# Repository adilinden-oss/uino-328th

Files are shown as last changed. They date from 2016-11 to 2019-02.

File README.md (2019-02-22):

## \*uino-328th

The \*uino-328th was designed for my son Mathew. As a mostly though-hole design, it should be easy to assemble even for a beginner.  The only surface mount component is the micro USB connector. Personally I much prefer micro USB over the full sized or mini connector. Unfortunately I was unable to find a through-hole micro USB.  Having the one surface mounted component was a compromise I was willing to take.

The board includes a USB serial bridge based on the PIC16F1454.  Not only is the PIC16F1454 available as a 14 pin though-hole device, it is also considerably less expensive then an ATmega8U2, for example.  

Initially I intend on using the [jgeisler0303/PIC16F1454_USB2Serial](https://github.com/jgeisler0303/PIC16F1454_USB2Serial)  firmware, but ultimately I hope to use the Open Source [signal11/m-stack](https://github.com/signal11/m-stack) as USB serial bridge firmware.

The \*uino-328th is intended to operate at 3.3V.  There are two possible clock sources for the ATmega328P, a dedicated resonator or the clock output of the PIC16F1454.

### Important Note

PCB have been ordered from SeeedStudio FusionPCB service. There is no working sample yet.

### Licensing

This work is licensed under a Creative Commons Attribution-ShareAlike 3.0 Unported License, CC BY-SA.

You are free to copy, distribute and transmit the work. You must attribute the work in the manner specified by the author or licensor (but not in any way that suggests that they endorse you or your use of the work). you alter, transform, or build upon this work, you may distribute the resulting work only under the same or similar license to this one.  

Please refer to [http://creativecommons.org/licenses/by-sa/3.0/] for the license.

### Credit

The \*uino-328th was inspired by:

- The Frienduino [jgeisler0303/Frienduino](https://github.com/jgeisler0303/Frienduino)
- The [Innovation Board](http://make.unl.edu/innovation-board/)

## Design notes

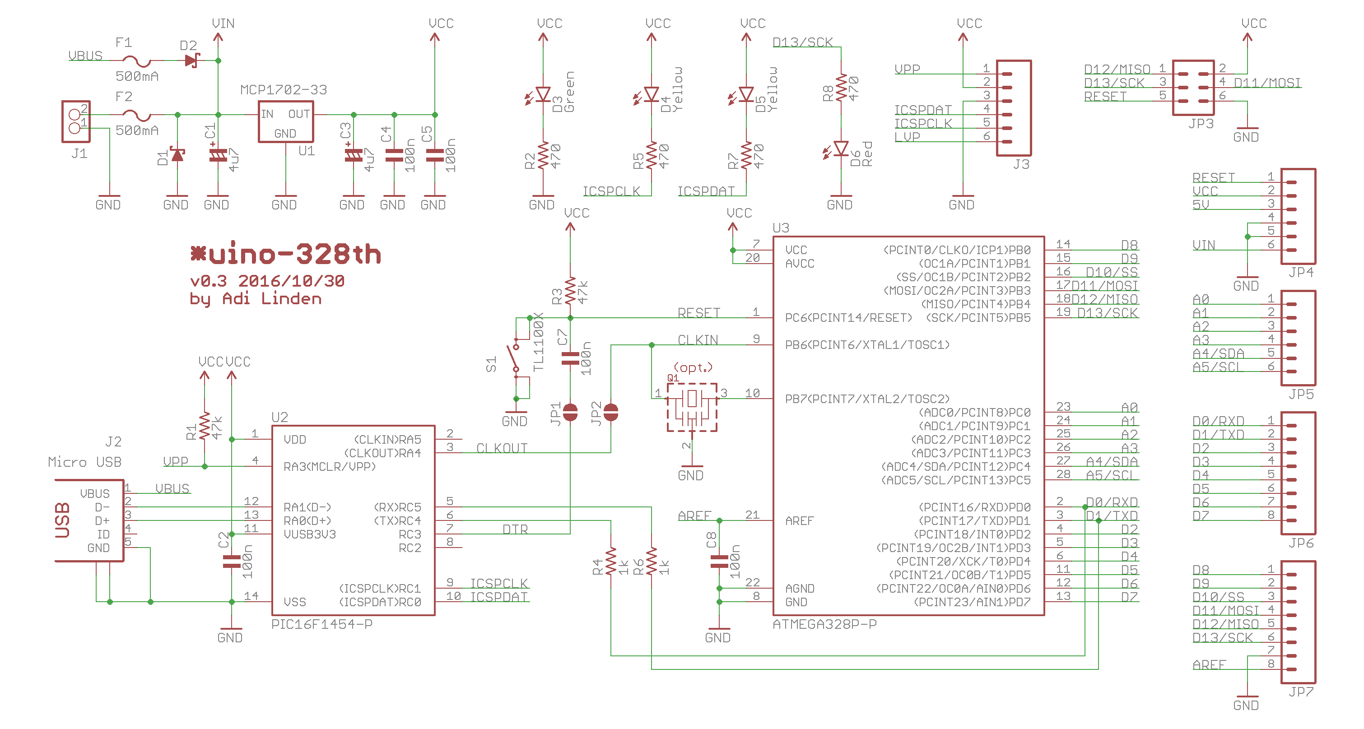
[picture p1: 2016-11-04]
uino-328th-sch.png

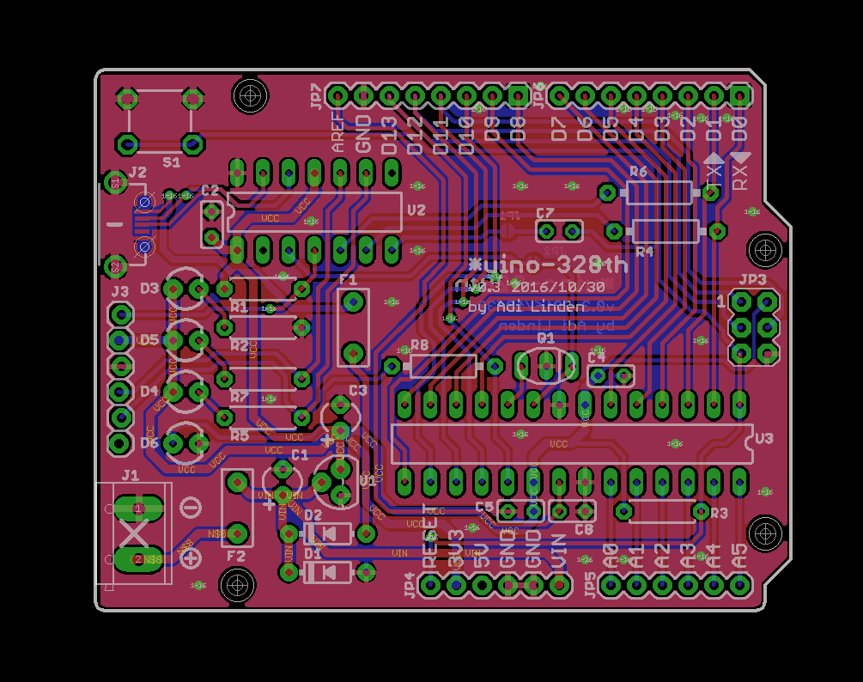
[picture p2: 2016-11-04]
uino-328th-brd.png

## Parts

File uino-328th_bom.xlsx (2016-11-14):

Parts | Qty | Value | Manufacturer Part Number | DigiKey Part Number | Package | Description
C1, C3 | 2 | 4u7 | TAP475M010SCS | 478-8841-ND | 2.5mm | 4.7µF ±20% Conformal Coated Tantalum Capacitors 10V Radial 8 Ohm
C2, C4, C5, C7, C8 | 5 | 100n | K104Z15Y5VF5TL2 | BC1160CT-ND | 2.5mm | 0.10µF -20%, +80% 50V Ceramic Capacitor Y5V (F) Radial
D1, D2 | 2 | 1A | SB140TA | 1655-1514-1-ND | DO-41 | Diode Schottky 40V 1A Through Hole DO-41
D3 | 1 | Green | HLMP1540 | 1080-1046-ND | LED3MM | Green LED Indication - Discrete 2.2V Radial
D4, D5 | 2 | Yellow | 151033YS03000 | 732-5014-ND | LED3MM | Yellow 589nm LED Indication - Discrete 2V Radial
D6 | 1 | Red | 151033RS03000 | 732-5013-ND | LED3MM | Red 621nm LED Indication - Discrete 2V Radial
F1, F2 | 2 | 400mA | 0ZRC0040FF1E | 507-1335-ND | 5mm | PTC Resettable Fuse 90V 400mA Ih Through Hole Radial, Disc
J1 | 1 | CON_TERMINAL_BLOCK_02-5MM | OSTTC022162 | ED2609-ND | 5mm | 2 Position Wire to Board Terminal Block Horizontal with Board 0.200" (5.08mm) Through Hole
J2 | 1 | Micro USB | 475890001 | WM17143CT-ND | ZX62D-AB-5P8 | USB - micro AB Receptacle Connector 5 Position Surface Mount, Right Angle, Horizontal
J3 | 1 | Header 1x6 | M20-9990645 | 952-2269-ND | 1X06 | 6 Positions Header, Unshrouded, Breakaway Connector 0.100" (2.54mm) Through Hole Gold
JP3 | 1 | Header 2x3 | M20-9980345 | 952-2120-ND | 2X03 | 6 Positions Header, Unshrouded, Breakaway Connector 0.100" (2.54mm) Through Hole Gold
JP4, JP5 | 2 | Header 1x6 | PPTC061LFBN-RC | S7004-ND | 1X06 | 6 Position Header Connector 0.100" (2.54mm) Through Hole Tin
JP6, JP7 | 2 | Header 1x8 | PPTC081LFBN-RC | S7006-ND | 1X08 | 8 Position Header Connector 0.100" (2.54mm) Through Hole Tin
Q1 | 1 | 12MHz | AWCR-12.00RS | 535-13413-ND | CSTLS_X | 12MHz Ceramic Resonator Built in Capacitor 15pF ±0.5% 25 Ohm -25°C ~ 85°C Through Hole
R1, R3 | 2 | 47k | CF14JT47K0 | CF14JT47K0CT-ND | 0207/7 | RES 47K OHM 1/4W 5% CARBON FILM
R2, R5, R7,R8 | 3 | 470 | CF14JT470R | CF14JT470RCT-ND | 0207/7 | RES 470 OHM 1/4W 5% CARBON FILM
R4, R6 | 2 | 1k | CF14JT1K00 | CF14JT1K00CT-ND | 0207/10 | RES 1K OHM 1/4W 5% CARBON FILM
S1 | 1 | Tactile Switch | 1825910-6 | 450-1650-ND | TL1100X | Tactile Switch SPST-NO Top Actuated Through Hole
U1 | 1 | MCP1702-33 | MCP1702-3302E/TO | MCP1702-3302E/TO-ND | TO-92 | Linear Voltage Regulator IC Positive Fixed 1 Output 3.3V 250mA TO-92-3
U2 | 1 | PIC16F1454-I/P | PIC16F1454-I/P | PIC16F1454-I/P-ND | DIL14 | PIC PIC® XLP™ 16F Microcontroller IC 8-Bit 48MHz 14KB (8K x 14) FLASH 14-PDIP
U3 | 1 | ATMEGA328P-PU | ATMEGA328P-PU | ATMEGA328P-PU-ND | DIL28-3 | AVR AVR® ATmega Microcontroller IC 8-Bit 20MHz 32KB (16K x 16) FLASH 28-PDIP

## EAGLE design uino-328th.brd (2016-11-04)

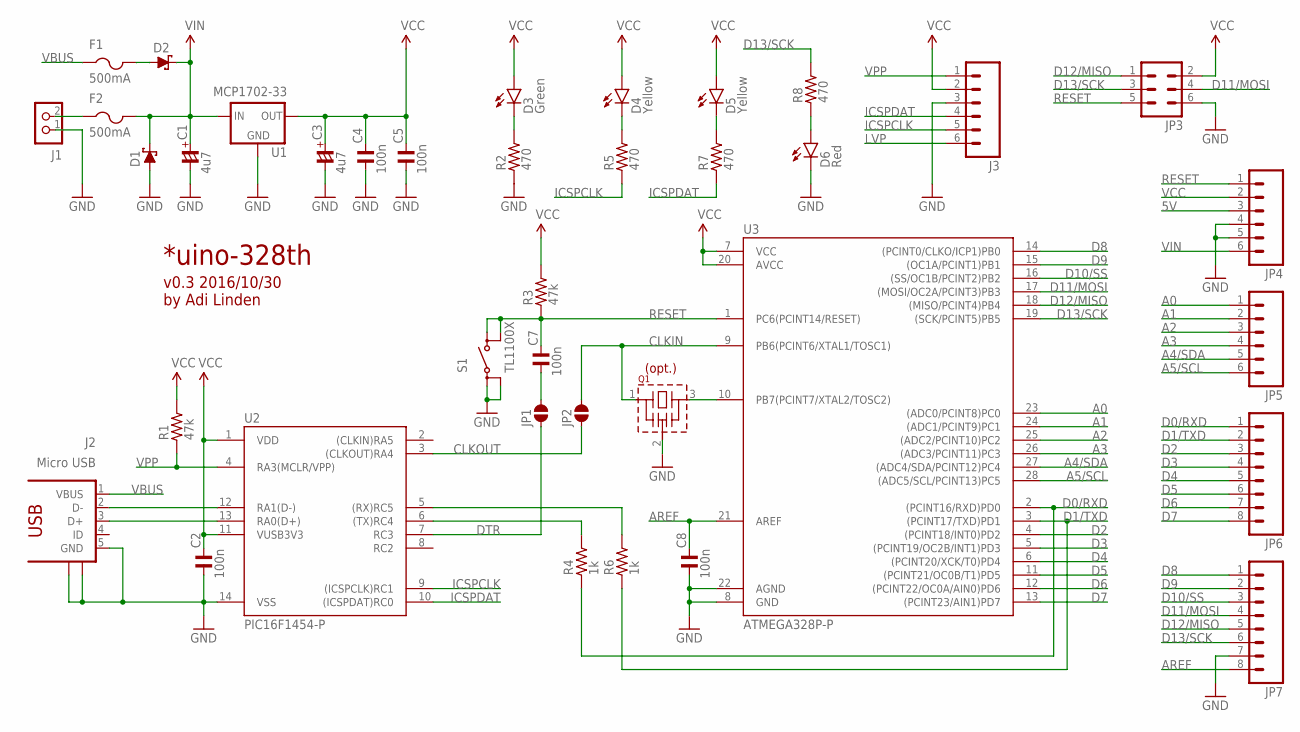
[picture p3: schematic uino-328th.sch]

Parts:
C1, C3: 4u7; CTT-025-040
C2, C4, C5, C7, C8: 100n; C025-040X018
D1, D2: SCHOTTKY-DIODEDO35-7; DO35-7
D3: Green; LED3MM
D4, D5: Yellow; LED3MM
D6: Red; LED3MM
F1, F2: 500mA; PTC
J1: CON_TERMINAL_BLOCK_02-5MM; TERMINAL_BLOCK_2P_5
J2: Micro USB; ZX62D-AB-5P8
J3: M06LOCK; 1X06_LOCK
JP1, JP2: SJ-035
JP3: M03X2; 2X03
JP4, JP5: M06SIP; 1X06
JP6, JP7: M081X08; 1X08
Q1: CSTLS_X
R1, R3: 47k; 0207/7
R2, R5, R7: 470; 0207/7
R4, R6: 1k; 0207/10
R8: 470; 0207/10
S1: TL1100X
U1: MCP1702-33; TO-92
U2: PIC16F1454-P; DIL14
U3: ATMEGA328P-P; DIL28-3

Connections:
5V: JP4.3
A0: JP5.1, U3.23 ((ADC0/PCINT8)PC0)
A1: JP5.2, U3.24 ((ADC1/PCINT9)PC1)
A2: JP5.3, U3.25 ((ADC2/PCINT10)PC2)
A3: JP5.4, U3.26 ((ADC3/PCINT11)PC3)
A4/SDA: JP5.5, U3.27 ((ADC4/SDA/PCINT12)PC4)
A5/SCL: JP5.6, U3.28 ((ADC5/SCL/PCINT13)PC5)
AREF: C8.2, JP7.8, U3.21 (AREF)
CLKIN: JP2.2, Q1.1, U3.9 (PB6(PCINT6/XTAL1/TOSC1))
CLKOUT: JP2.1, U2.3 ((CLKOUT)RA4)
D0/RXD: JP6.1, R4.1, U3.2 ((PCINT16/RXD)PD0)
D1/TXD: JP6.2, R6.1, U3.3 ((PCINT17/TXD)PD1)
D2: JP6.3, U3.4 ((PCINT18/INT0)PD2)
D3: JP6.4, U3.5 ((PCINT19/OC2B/INT1)PD3)
D4: JP6.5, U3.6 ((PCINT20/XCK/T0)PD4)
D5: JP6.6, U3.11 ((PCINT21/OC0B/T1)PD5)
D6: JP6.7, U3.12 ((PCINT22/OC0A/AIN0)PD6)
D7: JP6.8, U3.13 ((PCINT23/AIN1)PD7)
D8: JP7.1, U3.14 ((PCINT0/CLKO/ICP1)PB0)
D9: JP7.2, U3.15 ((OC1A/PCINT1)PB1)
D10/SS: JP7.3, U3.16 ((SS/OC1B/PCINT2)PB2)
D11/MOSI: JP3.4, JP7.4, U3.17 ((MOSI/OC2A/PCINT3)PB3)
D12/MISO: JP3.1, JP7.5, U3.18 ((MISO/PCINT4)PB4)
D13/SCK: JP3.3, JP7.6, R8.2, U3.19 ((SCK/PCINT5)PB5)
DTR: JP1.1, U2.7 (RC3)
GND: C1.-, C2.1, C3.-, C4.1, C5.1, C8.1, D1.A, D6.K (C), J1.1, J2.5 (GND), J2.S1, J2.S2, J3.3, JP3.6, JP4.4, JP4.5, JP7.7, Q1.2 (VSS), R2.1, S1.1, S1.2 (P1), U1.1 (GND), U2.14 (VSS), U3.8 (GND), U3.22 (AGND)
ICSPCLK: J3.5, R5.1, U2.9 ((ICSPCLK)RC1)
ICSPDAT: J3.4, R7.1, U2.10 ((ICSPDAT)RC0)
LVP: J3.6
unnamed: D3.K (C), R2.2
unnamed: C7.1, JP1.2
unnamed: J2.2 (D-), U2.12 (RA1(D-))
unnamed: J2.3 (D+), U2.13 (RA0(D+))
unnamed: D6.A, R8.1
unnamed: F2.P$1 (1), J1.2
unnamed: R4.2, U2.6 ((TX)RC4)
unnamed: R6.2, U2.5 ((RX)RC5)
unnamed: Q1.3, U3.10 (PB7(PCINT7/XTAL2/TOSC2))
unnamed: D4.K (C), R5.2
unnamed: D5.K (C), R7.2
unnamed: D2.A, F1.P$2 (2)
RESET: C7.2, JP3.5, JP4.1, R3.1, S1.3 (S), S1.4 (S1), U3.1 (PC6(PCINT14/RESET))
VBUS: F1.P$1 (1), J2.1 (VBUS)
VCC: C2.2, C3.+, C4.2, C5.2, D3.A, D4.A, D5.A, J3.2, JP3.2, JP4.2, R1.2, R3.2, U1.3 (OUT), U2.1 (VDD), U2.11 (VUSB3V3), U3.7 (VCC), U3.20 (AVCC)
VIN: C1.+, D1.C, D2.C, F2.P$2 (2), JP4.6, U1.2 (IN)
VPP: J3.1, R1.1, U2.4 (RA3(MCLR/VPP))

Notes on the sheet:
*uino-328th
v0.3 2016/10/30 by Adi Linden
(opt.)

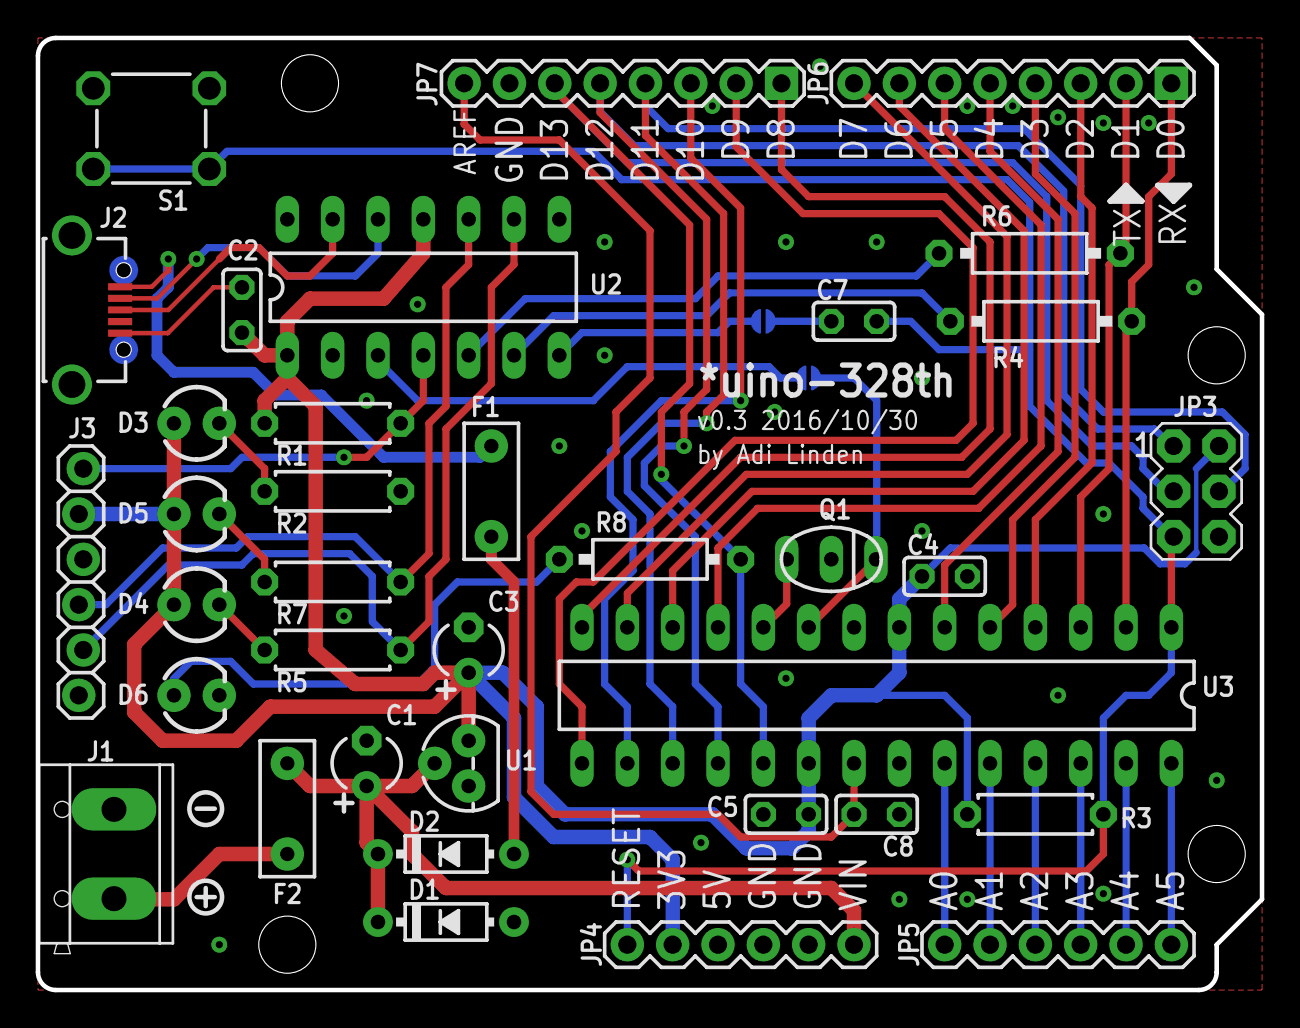
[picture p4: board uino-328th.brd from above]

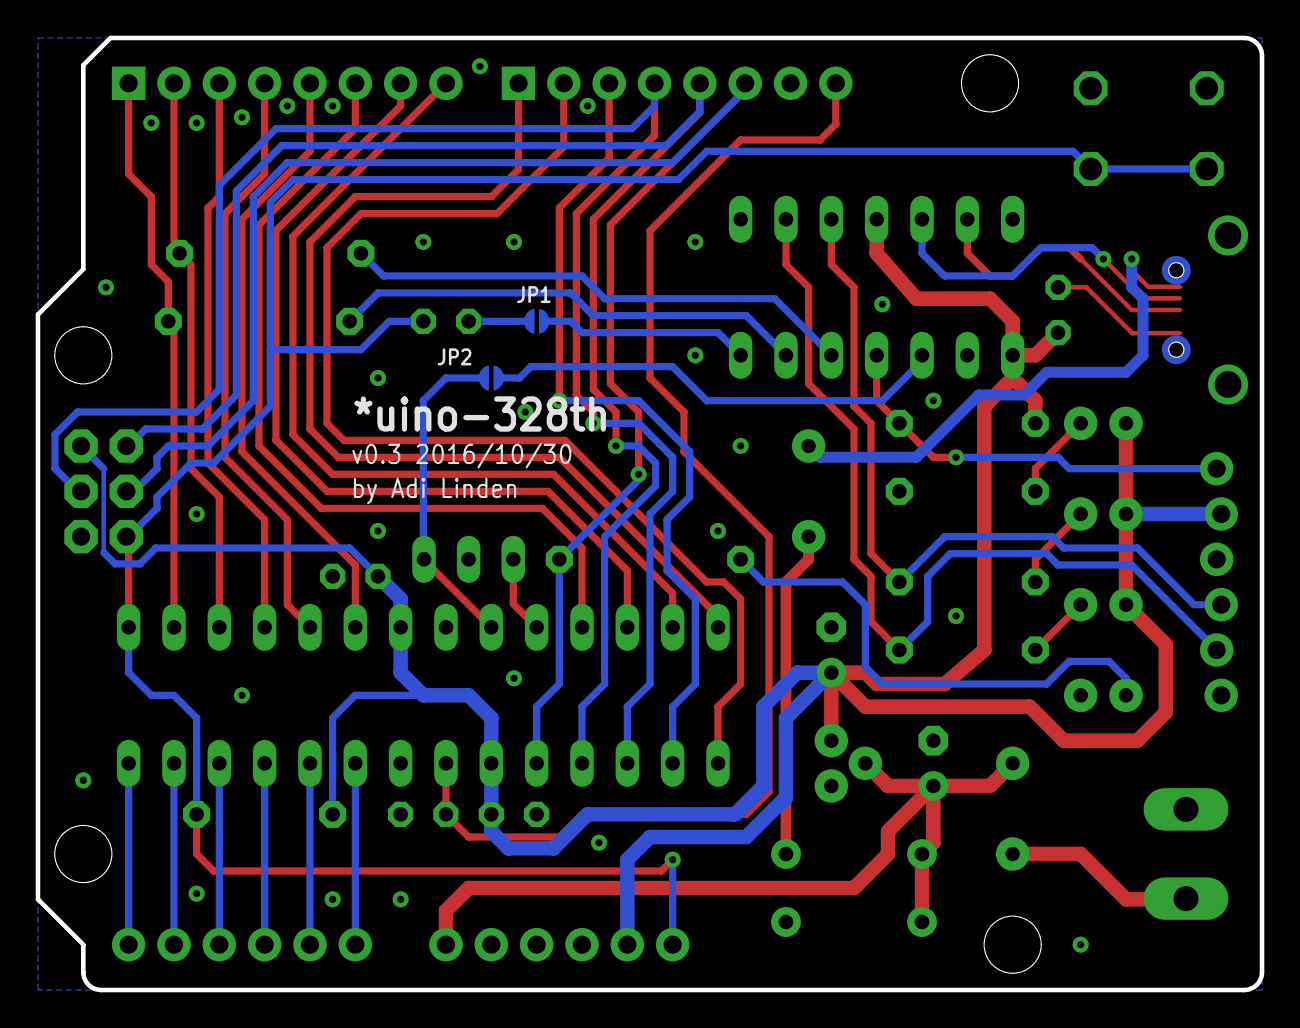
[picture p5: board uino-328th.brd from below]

Board: 2 copper layers, 68.6 x 53.3 mm, 38 parts (2 on the bottom side), 44 nets.

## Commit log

2016-10-24 Added new project.
    [uino-328th.brd, uino-328th.sch]
2016-10-25 Schematic complete.
    [uino-328th.brd, uino-328th.sch]
2016-10-26 Changed to 3V3 and 5V hybrid.
    [uino-328th.brd, uino-328th.sch]
2016-10-27 Attempts at routing board.
    [uino-328th.brd, uino-328th.sch]
2016-10-30 First cut to try gerber.
    [uino-328th.brd, uino-328th.sch]
2016-10-31 Some minor final changes.
    [uino-328th.brd, uino-328th.sch]
2016-10-31 Ran cam jon to create gerber.
2016-11-04 Added values. Added png files.
    [uino-328th.brd, uino-328th.sch]
2016-11-14 Added BOM.
    [uino-328th_bom.xlsx]

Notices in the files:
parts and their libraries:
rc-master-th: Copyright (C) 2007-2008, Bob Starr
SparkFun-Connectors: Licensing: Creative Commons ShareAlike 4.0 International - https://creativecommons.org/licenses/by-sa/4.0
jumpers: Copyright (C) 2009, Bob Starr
